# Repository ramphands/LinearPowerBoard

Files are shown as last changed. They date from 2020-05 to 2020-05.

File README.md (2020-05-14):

# Linear Power Board for Eurorack

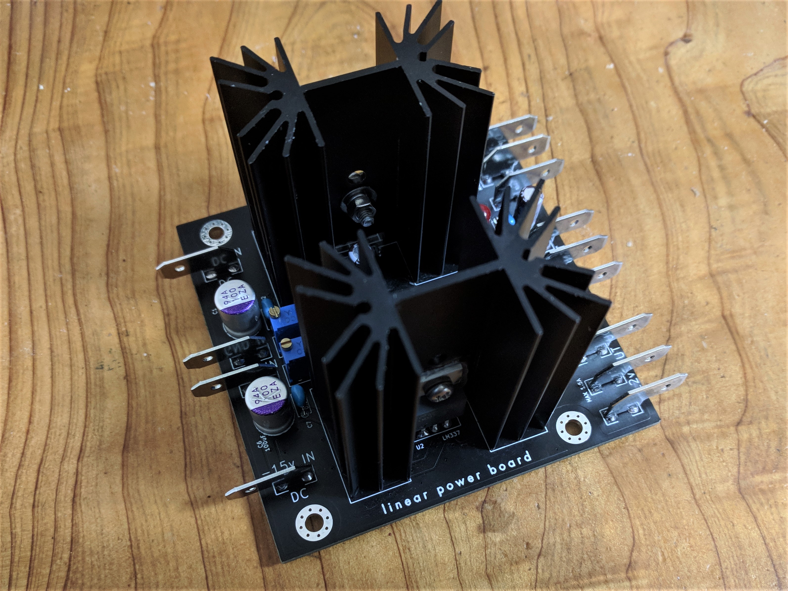
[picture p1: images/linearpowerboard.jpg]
linear power board

A board to take the input of two single-output 15v SMPS AC-DC PSUs and output a precise, regulated +/-12v DC to use in a Eurorack system.

Using two 15v single-supply SMPSs**, the board combines the negative output of one supply with the positive output of the other supply, forming a reference ground.  The remaining positive output provides +15v to the board's negative rail and the remaining negative output provides -15v to the board's negative rail.
The positive and negative rails are then filtered before being regulated by a LM350 on the positive rail and an LM337 on the negative rail.  The two regulators can be adjusted using a trimmer to achieve exactly +/-12v DC at (depending on the heatsink and supply chosen) up to 2A** on the positive rail and 1.5A on the negative.  This is roughly enough power for a 9U 104HP case.

The boards use blade/faston terminals to distribute power to the busboards.

Wiring for the board is as follows:
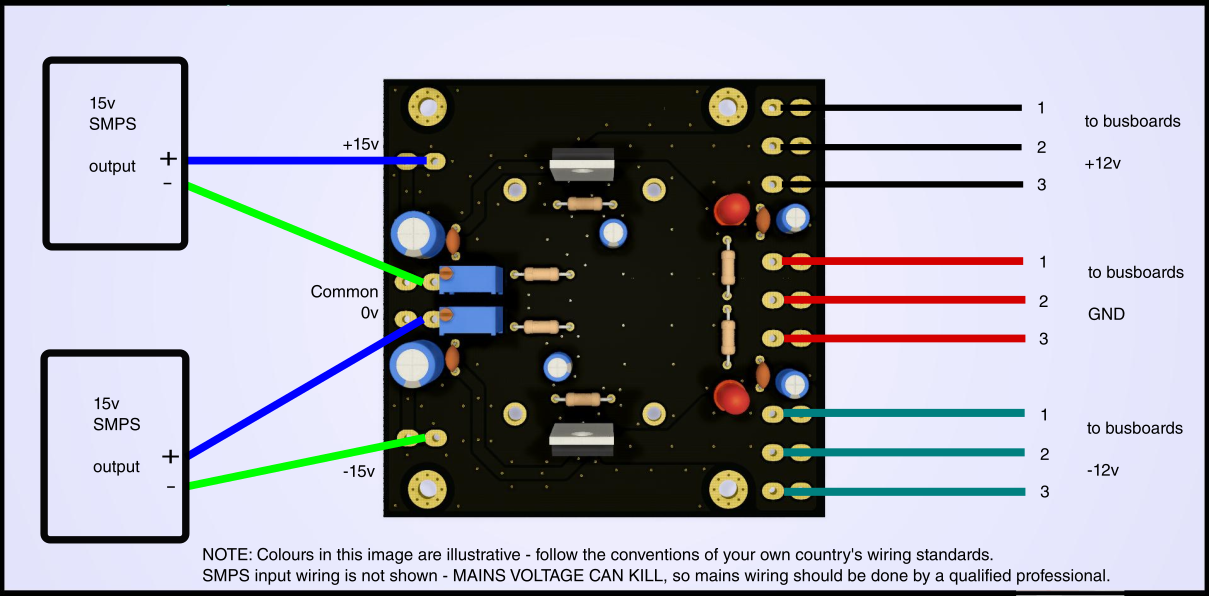
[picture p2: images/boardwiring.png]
wiring


An example of usage is as follows:
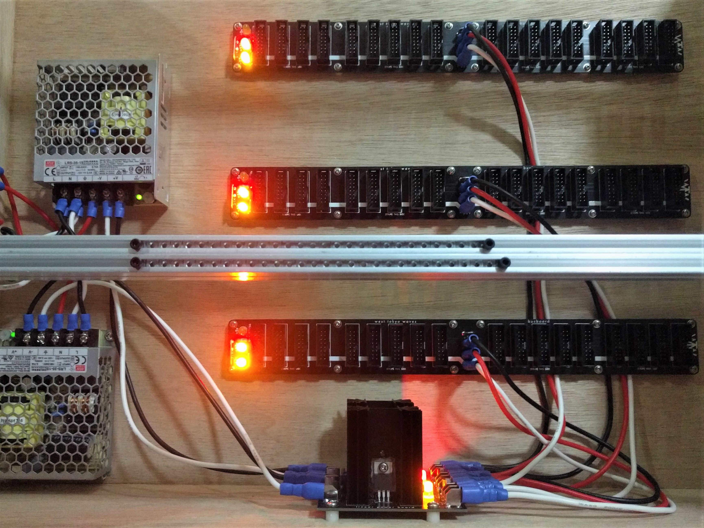
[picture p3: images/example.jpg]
powersupplyexample


There is no 5v regulator or rail provided due to its huge decline in usage.  If needed, please either use a busboard with a 5v regulator or a solution such as the Mutable Instruments Volts plug-in module.

** Common examples are the Mean Well RS-35-15, RS-50-15 or the smaller LRS-35-15 / LRS-50-15 (or similarly specced)

*** Theoretically it could provide  up to 3A, but you would need a very large heatsink with active cooling.

Project is CC BY-NC-SA 4.0

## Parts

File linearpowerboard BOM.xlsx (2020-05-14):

Linear Power Board
Reference | Qty | Desc | Value | Info. | Mouser part #
C1, C6 | 2 | Capacitor, Organic Polymer or Low ESR Electrolytic | 100uF | 35v Low ESR Radial 100uF Aluminum Organic Polymer Capacitor (3.5mm lead width) | 667-EEH-AZF1V101
C3, C5, C8, C10 | 4 | Capacitor, Low ESR Electrolytic | 10uF | Aluminum Electrolytic Capacitor - Radial Leaded 10uF 50 Volt | 661-EKY50ETD100ME11D
C2, C4, C7, C9 | 4 | Capacitor, Ceramic X7R | 0.1uf | 50v MLCC X7R | 810-FG28X7R1H104KNT0
D1 | 1 | LED, Red, 5mm | LED | Liteon 5mm LED Red Diffused | 859-LTL2R3KRD-EM
D2 | 1 | LED, Yellow, 5mm | LED | Liteon 5mm LED Yellow Diffused | 859-LTL2R3KYD-EM
HS1, HS2 | 2 | TO-220 Heatsink | Heatsink | Ohmite FA-T220-51E heat sink | 588-FA-T220-51E
J1-13 | 13 | Right-angle PCB mount quick disconnect | quick disconnect | Molex quick disconnect 6.35mm 0.250” flag pcb-mount tab | 538-19713-4001 (alternatively 571-928814-1)
R1, R4 | 2 | Resistor, 1/4W | 1.8k | 1.8k 1/4W resistor | 603-MFR-25FTF52-1K8
R2, R5 | 2 | Resistor, 1/4W | 220 | 220 ohm 1//4W resistor | 603-MFR-25FTE52-220R
R3, R6 | 2 | Resistor, 1/4W | 2.2k | 2.2k 1/4W resistor | 603-MFR-25FTF52-2K2
RV1, RV2 | 2 | Trimmer resistor, 25 turns, top adjust, Y lead spacing | 200 | Bourns 3296Y 200 ohm trimmer | 652-3296Y-1-201LF
U1 | 1 | Adjustable Linear Voltage Regulator 3A | LM350 | Texas Instruments LM350T(or LM350AT) TO-220 | 926-LM350T/NOPB
U2 | 1 | Adjustable Linear Negative Voltage Regulator 1.5A | LM337 | Texas Instruments LM337 TO-220 | 926-LM337T/NOPB
Additional items for heatsinks:
 | 2 | Insulating thermal interface sheet |  | Polyimide Plastic Film for TO-220 regulators | 532-43-77-9
 | 2 | Insulating washer |  | Insulating shoulder washer for TO-220 regulators | 532-7721-7PPS
 | 2 | M3x10 screws
 | 2 | M3 spring washers
 | 2 | M3 nuts
 |  | Non-conductive thermal compound |  | apply to both sides of the thermal interface sheet when attaching regulator to heatsink

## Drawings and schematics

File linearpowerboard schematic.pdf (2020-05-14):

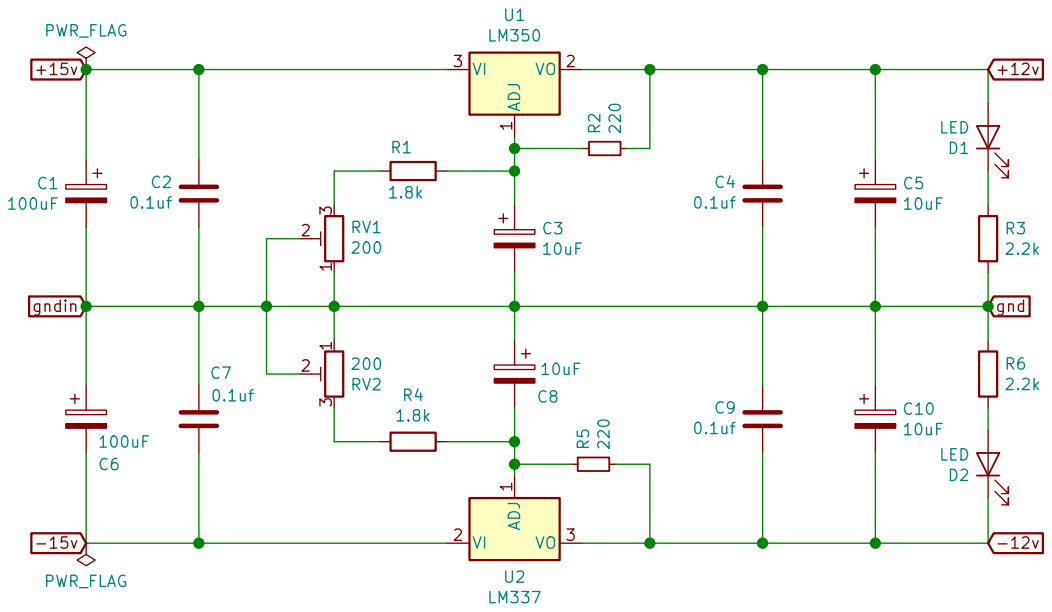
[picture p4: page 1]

File: linearpowerboard.sch Sheet: / West Tokyo Waves CC BY-NC-SA 4.0

Id: 1/1 Title: Linear Power Board

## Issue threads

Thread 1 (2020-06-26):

Breakout board schematics?

ethought, 2020-06-26:
Great project!! Thank you.

I am building several of these. Do you have the schematics for the breakout boards? I know they are simple but would be good to see yours.

ethought, 2020-06-26:
Sorry I meant schematics and gerber files for the breakout boards

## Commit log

2020-05-14 Add files via upload
    BOM with Mouser part numbers where applicable.
    [linearpowerboard BOM.xlsx]
2020-05-14 Add files via upload
    Schematic for linear power board
